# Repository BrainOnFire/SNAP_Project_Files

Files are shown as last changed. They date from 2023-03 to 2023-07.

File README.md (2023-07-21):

# S.N.A.P. Version 6.0

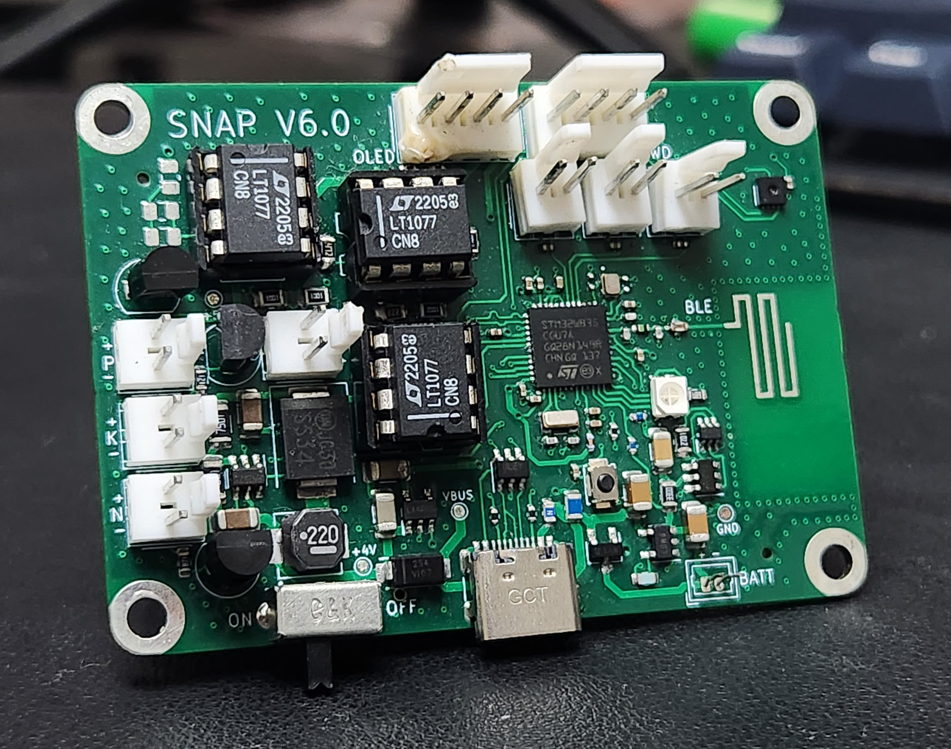
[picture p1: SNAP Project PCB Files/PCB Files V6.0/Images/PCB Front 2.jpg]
</a>

Soil Nutrient Analysis Prototype or S.N.A.P. for short, is an agricultural device that allows farmers to know the best type of nutrient present in a soil sample. The most common types of nutrients found in the ground are Nitrogen, Phosphorus, and Potassium. Photo-sensing sensors can observe these nutrients when an infrared beam hits a sample. Having this information in less than 10 minutes allows the farmer to decide which crop to plant in the selected soil, saving a lot of time and money. The device has come a long way, as this is the sixth iteration of the project. SNAP 6.0 is a BLE, Low-Power, feature-rich sensing device. Here are some specs of the device:

- STM32WB35CCU7A as main MCU (Ultra-low-power dual-core ARM Cortex-M4 with FPU, Bluetooth 5.2, 256KB Flash, 32MHz)
- Integrated Lithium-Ion battery charging with MCP73831 (Charge current 500mA, 4.2V Regulation, Reverse Discharge Protection)
- Battery protection using AP9101C (overcharge voltage, over-discharge voltage, overcharge current, over-discharge current)
- Boost Converter from 3.0V to 5.2V using MT3608 (turns on/off by MCU)
- Temperature and humidity sensing using SHT31-DIS
- OLED Screen for displaying information with low consumption
- PCB Antenna with impedance matching for Bluetooth Low Energy
- USB Type-C 2.0 for 5V power supply and communication

## PCB Design
The design and development of the printed circuit board were done using KiCAD 6.0. The PCB in question is a 4-layer board with a thickness of 1.62 mm and overall dimensions of 66.80 mm x 47.34 mm. The layer stack up is Signal - Ground - Ground - Mixed. 

A USB-C Type Receptacle was used for the power supply coupled with a USBLC6-2SC6 ESD protection chip. Serial Wire is used for the programming of the STM32 chip. A MOSFET and a Schottky Diode are used in order to protect the device when both battery and USB are connected and supply power to the system. Both inputs are regulated by the ADP121 LDO which outputs a voltage of 3.0V to the MCU and to the boost-up converter. The amplification system, the three IR LEDs, the Phototransistor, the SHT31, and the OLED screen are supplied by the 5.2V outputted by the boost-up converter MT3608. Three 2N700 MOSFETs are used to control the IR LEDs through the MCU. 

A total of 27 decoupling capacitors of different values and sizes are used to filter unwanted frequencies. 

A filter PI and RF Band Pass filter are used for the 2.4GHz PCB BLE antenna. The values of capacitance and inductance were calculated using the impedance of the PCB antenna (obtained from [AN5129](https://www.st.com/resource/en/application_note/an5129-low-cost-pcb-antenna-for-24ghz-radio-meander-design-for-stm32wb-series-stmicroelectronics.pdf)), in order to obtain a matching impedance of 50 ohms. The next two images show the first and second pages of the schematic; every part of the device is clearly named.

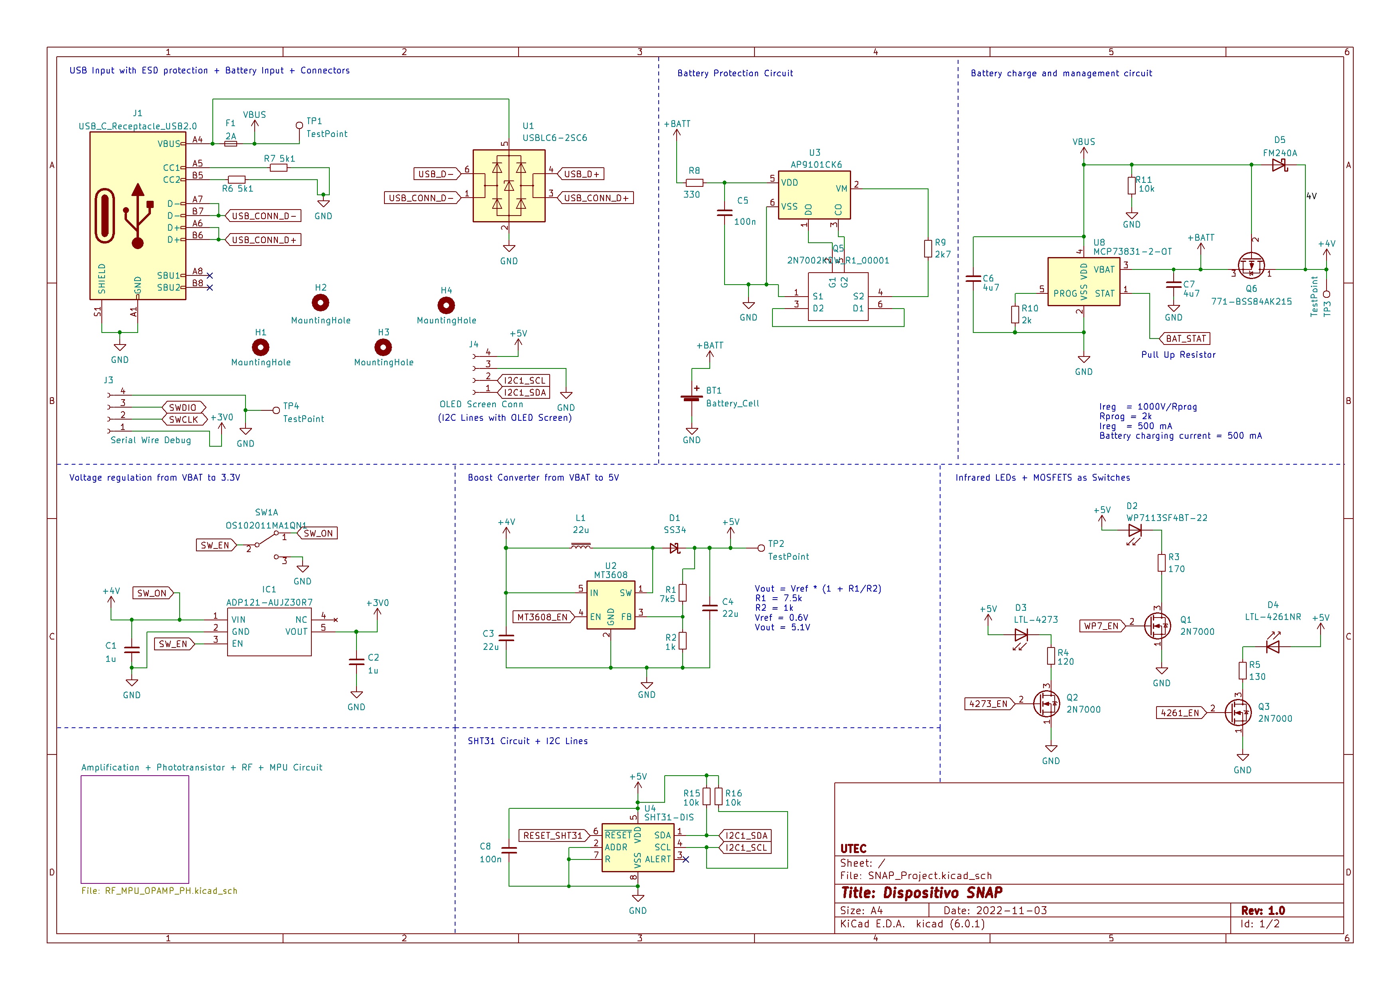
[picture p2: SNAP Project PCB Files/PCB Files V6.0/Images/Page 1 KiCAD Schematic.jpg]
</a>
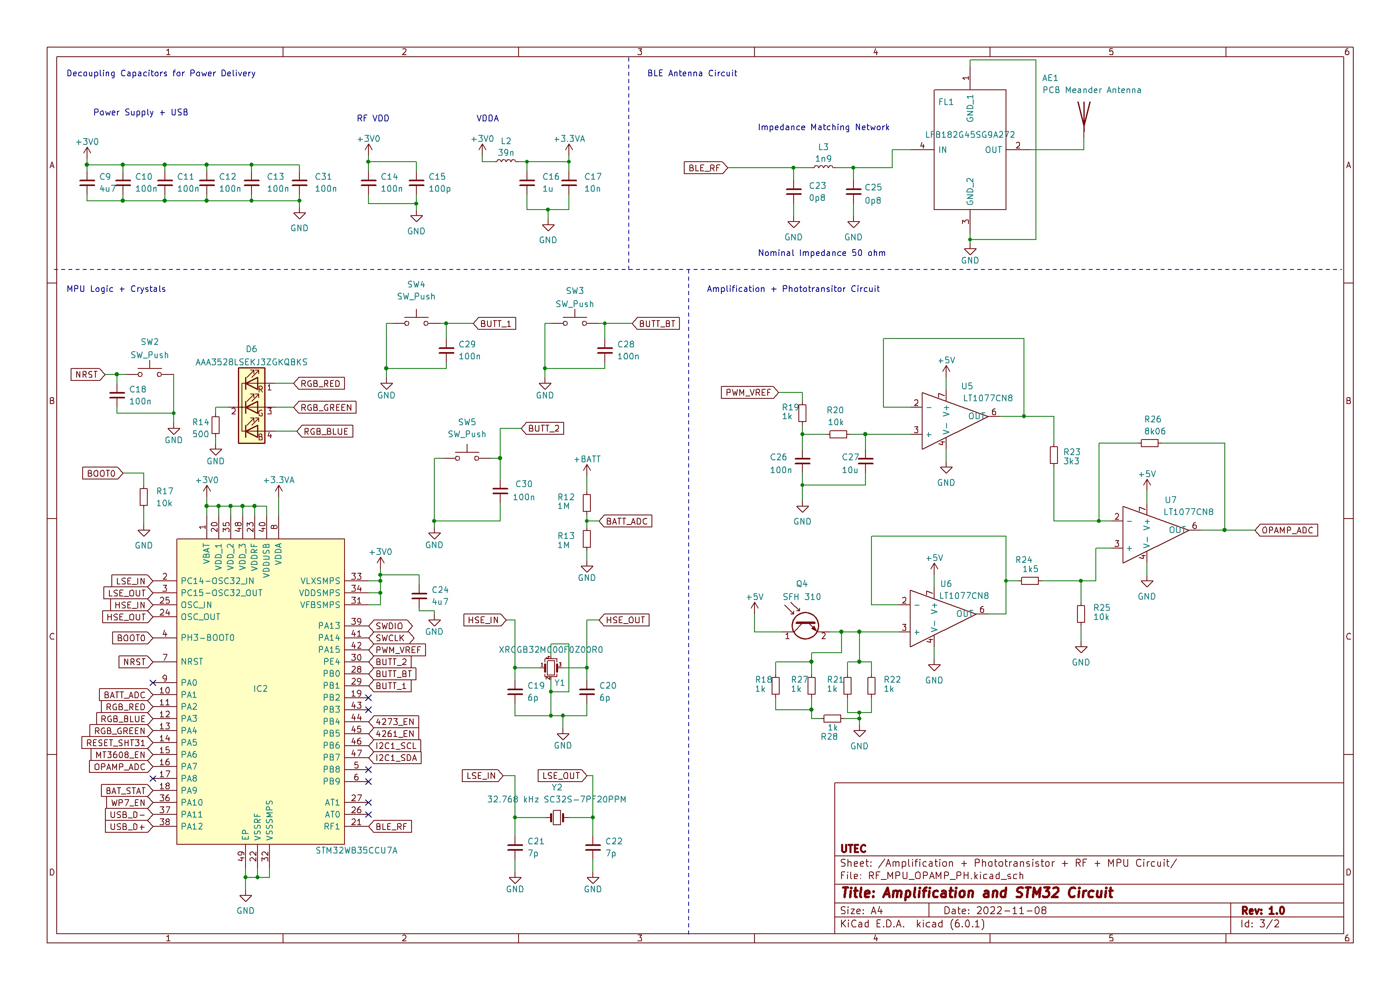
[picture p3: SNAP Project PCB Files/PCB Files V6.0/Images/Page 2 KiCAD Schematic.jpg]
</a>

This PCB was manufactured by JLCPCB using the controlled impedance stack up JLC04161H-7628 for a dielectric constant of 4.6. This provides a matching impedance of 50 ohm for the traces of the embedded antenna that mitigate potential power losses due to parasitic capacitances. The SMD components were soldered using an SMD reflow process with a heat gun.

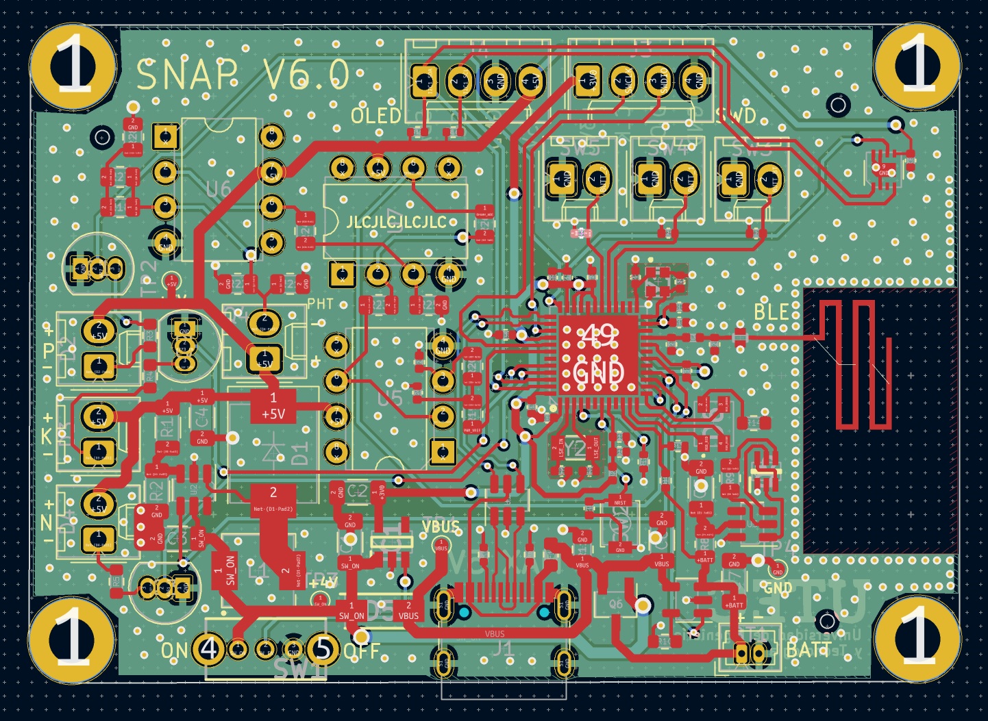
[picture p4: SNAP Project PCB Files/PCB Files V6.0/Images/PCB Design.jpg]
</a>
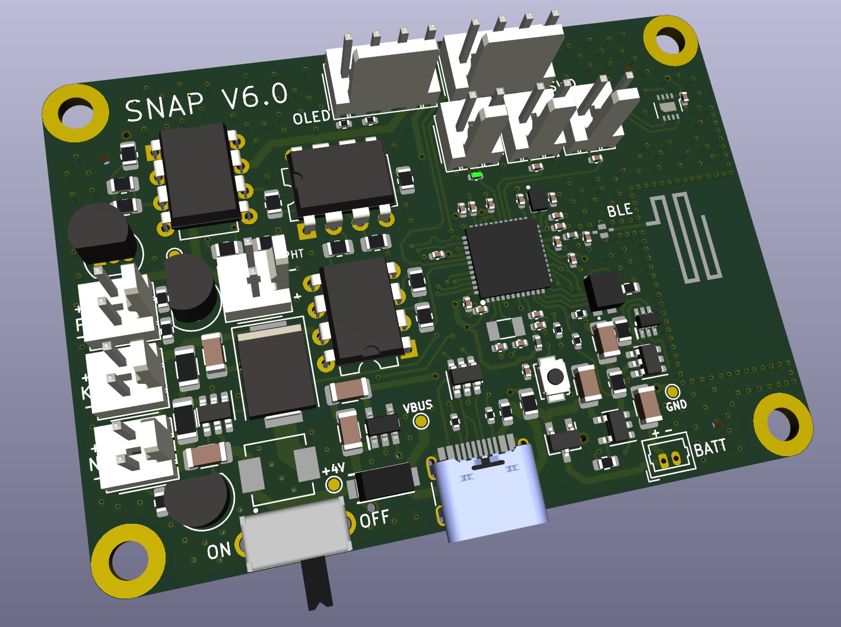
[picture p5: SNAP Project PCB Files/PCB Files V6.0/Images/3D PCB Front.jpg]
</a>

Most of the components were selected for the sole purpose of low energy consumption. The battery selected was a 2500mAh LiPo battery which can be charged through the device's USB type C. With this battery capacity, the device is capable of lasting for almost 30 days without charging, while being completely on. If the device's switch is turned OFF, the battery can last for almost a year and a half without the need for charging. Using a special Fluke Ammeter the total consumption of the device in this state is 185nA. This consumption happens because the device is not completely OFF; some components of the battery's charging system and the LDO are still drawing some current. The challenge of this device's design was keeping the consumption to a minimum. The team is very satisfied with the results.

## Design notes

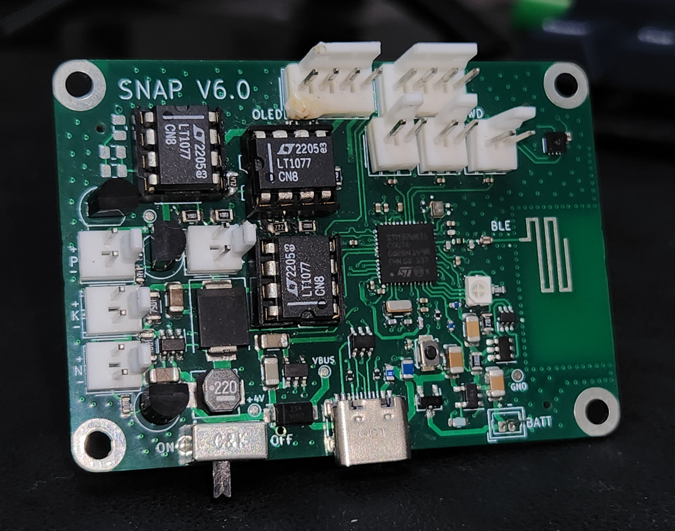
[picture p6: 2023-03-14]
SNAP Project PCB Files/PCB Files V6.0/Images/PCB Front 1.jpg

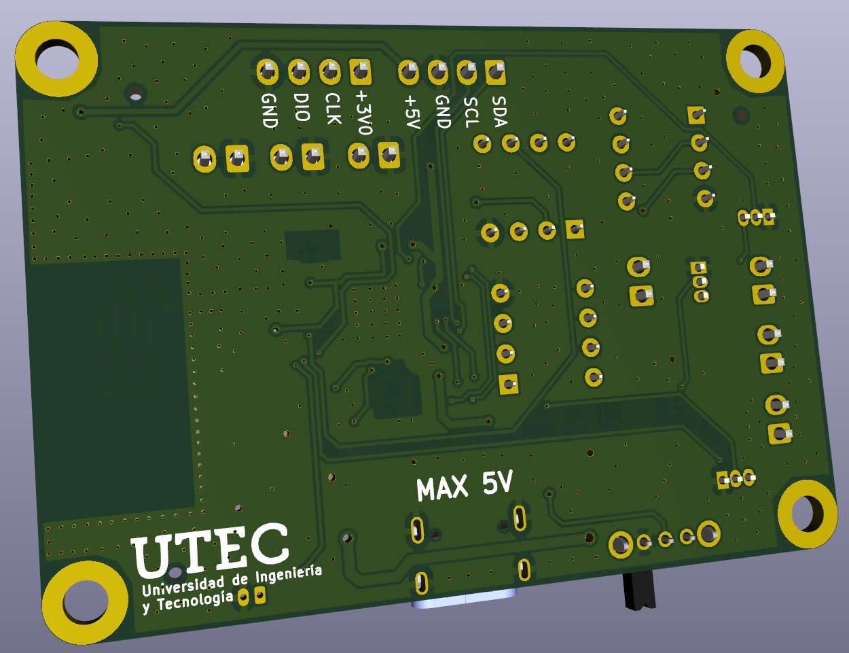
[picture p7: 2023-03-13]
SNAP Project PCB Files/PCB Files V6.0/Images/3D PCB Back.jpg

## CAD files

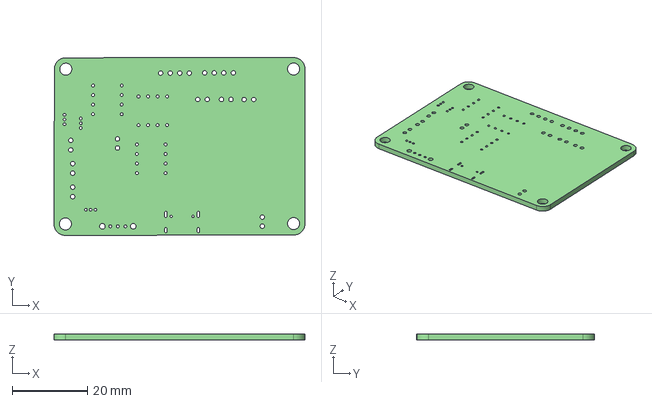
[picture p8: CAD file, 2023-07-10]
SNAP Project PCB Files/PCB Files V6.0/3D Files/SNAP_Project.step
66.7 x 47.2 x 1.63 mm

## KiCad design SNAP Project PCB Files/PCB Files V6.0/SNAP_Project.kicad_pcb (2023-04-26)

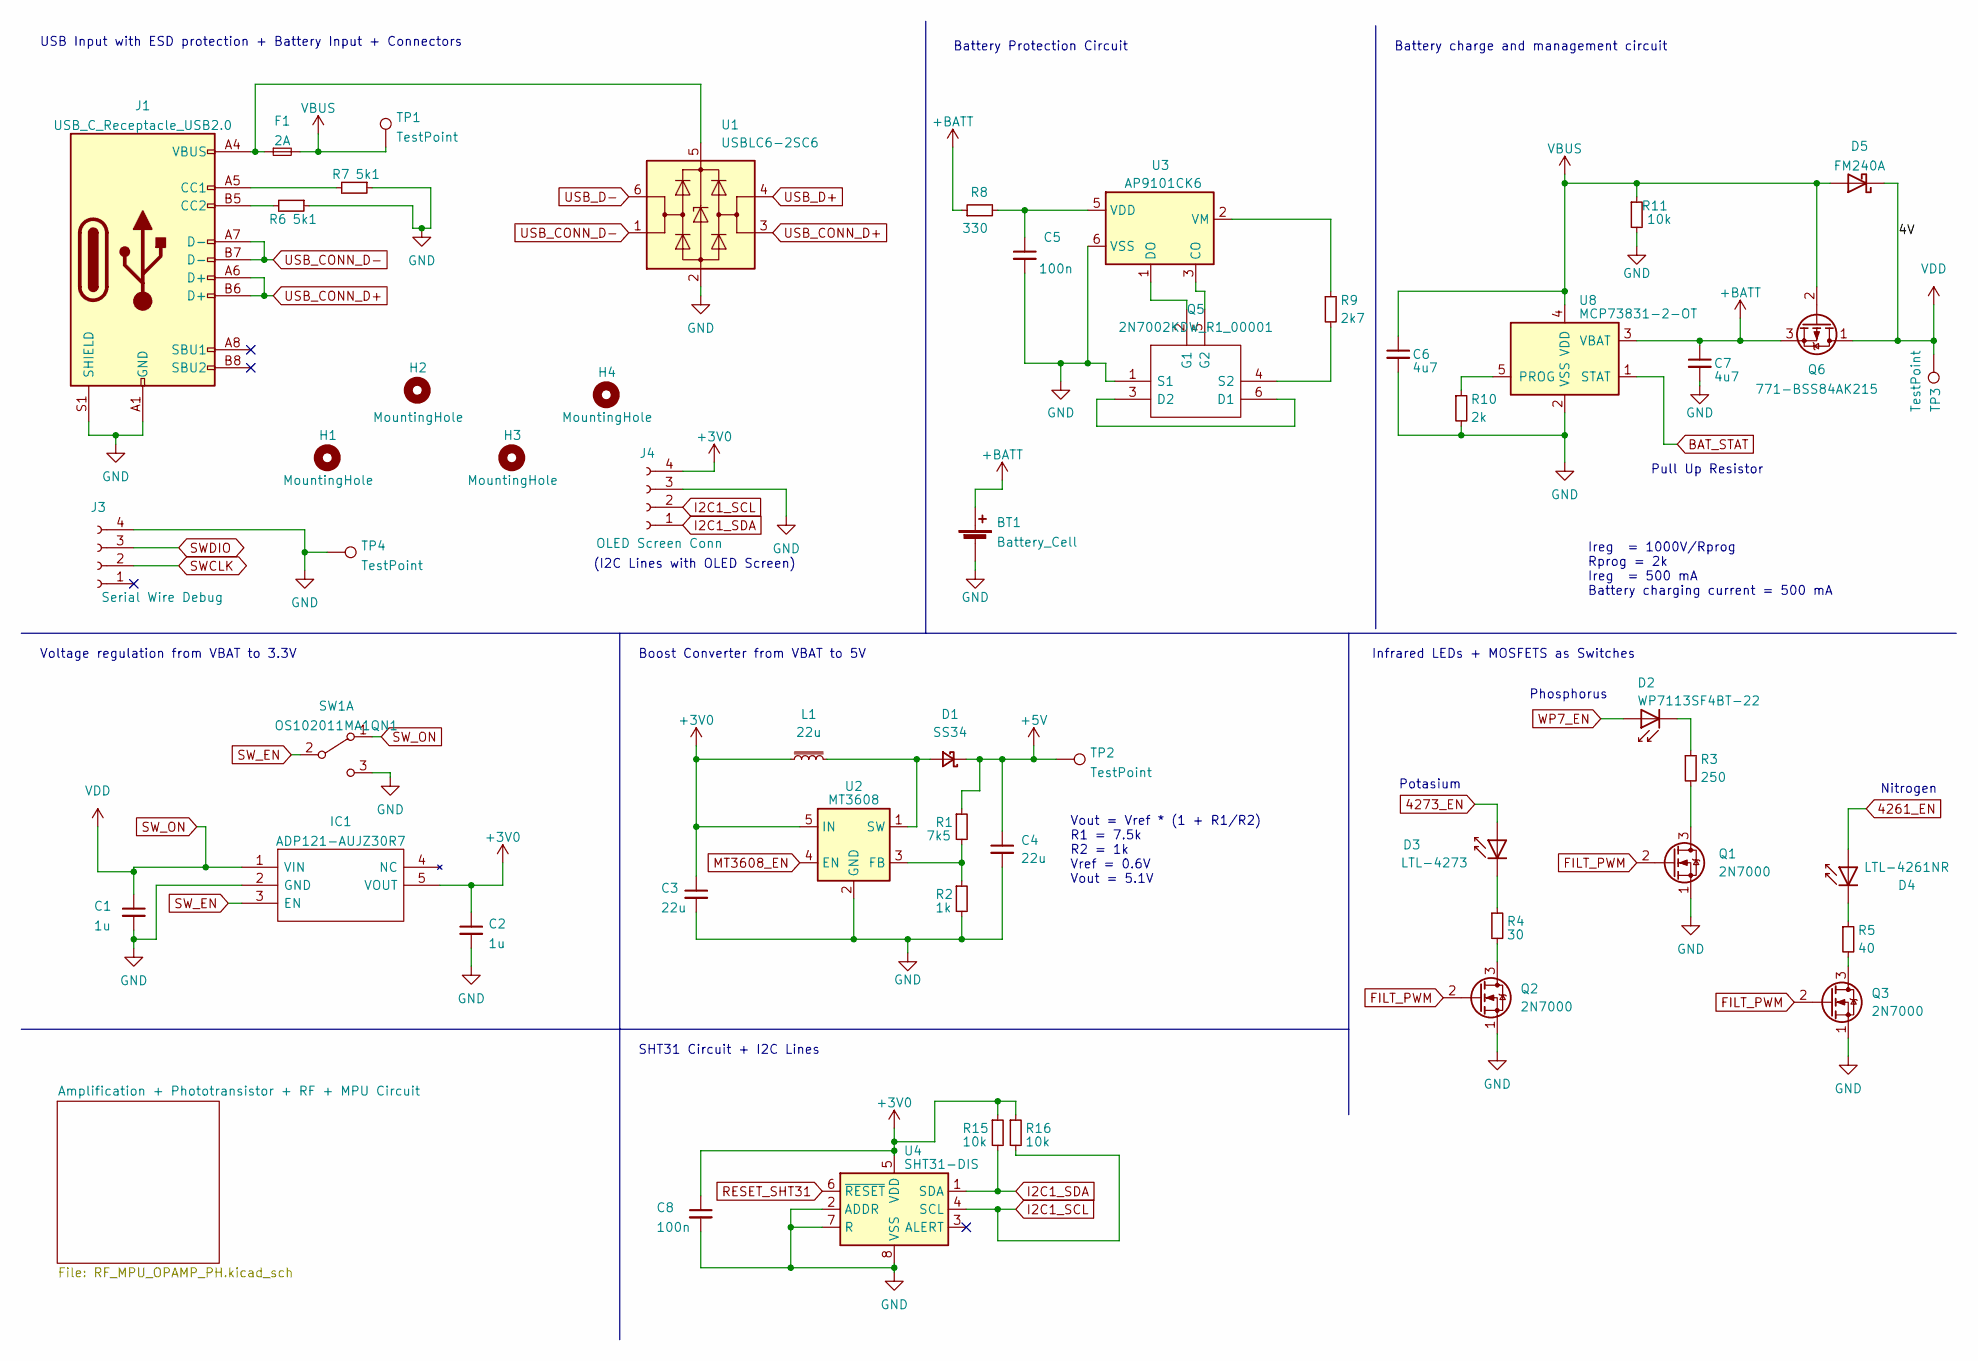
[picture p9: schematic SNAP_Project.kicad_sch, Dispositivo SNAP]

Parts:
BT1: Battery_Cell; Molex_KK-254_AE-6410-02A_1x02_P2.54mm_Vertical
C1, C2: 1u; C_1206_3216Metric
C3, C4: 22u; C_1206_3216Metric
C5: 100n; C_1206_3216Metric
C6, C7: 4u7; C_1206_3216Metric
C8: 100n; C_0402_1005Metric
D1: SS34; D_SMC
D2: WP7113SF4BT-22; Molex_KK-254_AE-6410-02A_1x02_P2.54mm_Vertical
D3: LTL-4273; Molex_KK-254_AE-6410-02A_1x02_P2.54mm_Vertical
D4: LTL-4261NR; Molex_KK-254_AE-6410-02A_1x02_P2.54mm_Vertical
D5: FM240A; DIOM5025X231N
F1: 2A; Fuse_0603_1608Metric; Mouser Code MFU0603FF02000P500
H1, H2, H3, H4: MountingHole; MountingHole_3mm_Pad
IC1: ADP121-AUJZ30R7; SOT95P280X100-5N; Mouser Part Number 584-ADP121-AUJZ33R7
J1: USB_C_Receptacle_USB2.0; USB_C_Receptacle_HRO_TYPE-C-31-M-12
J3: Serial Wire Debug; Molex_KK-254_AE-6410-04A_1x04_P2.54mm_Vertical
J4: OLED Screen Conn; Molex_KK-254_AE-6410-04A_1x04_P2.54mm_Vertical
L1: 22u; L_Vishay_IHLP-2020
Q1, Q2, Q3: 2N7000; TO-92_Inline
Q5: 2N7002KDW_R1_00001; SOT65P210X110-6N; Mouser Part Number 241-2N7002KDWR100001
Q6: 771-BSS84AK215; TSOT-23
R1: 7k5; R_1206_3216Metric
R2: 1k; R_1206_3216Metric
R3: 250; R_0805_2012Metric
R4: 30; R_0603_1608Metric
R5: 40; R_0603_1608Metric
R6, R7: 5k1; R_0402_1005Metric
R8: 330; R_0805_2012Metric
R9: 2k7; R_0805_2012Metric
R10: 2k; R_0603_1608Metric
R11: 10k; R_0805_2012Metric
R15, R16: 10k; R_0402_1005Metric
SW1: OS102011MA1QN1
TP1, TP2, TP3, TP4: TestPoint; TestPoint_Pad_D1.0mm
U1: USBLC6-2SC6; SOT-23-6
U2: MT3608; SOT-23-6
U3: AP9101CK6; SOT-23-6
U4: SHT31-DIS; Sensirion_DFN-8-1EP_2.5x2.5mm_P0.5mm_EP1.1x1.7mm
U8: MCP73831-2-OT; SOT-23-5

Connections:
4261_EN: D4.2 (A); also elsewhere on the board
4273_EN: D3.2 (A); also elsewhere on the board
+3V0: C2.1, C3.1, C8.1, IC1.5 (VOUT), J4.4, L1.1, R15.1, R16.1, U2.5 (IN), U4.5 (VDD); also elsewhere on the board
+5V: C4.1, D1.1 (K), R1.1, TP2.1; also elsewhere on the board
+BATT: BT1.1 (+), C7.1, Q6.3 (S), R8.1, U8.3 (VBAT); also elsewhere on the board
BAT_STAT: U8.1 (STAT); also elsewhere on the board
FILT_PWM: Q1.2 (G), Q2.2 (G), Q3.2 (G); also elsewhere on the board
GND: BT1.2 (-), C1.2, C2.2, C3.2, C4.2, C5.2, C6.2, C7.2, C8.2, IC1.2 (GND), J1.A1 (GND), J1.A12 (GND), J1.B1 (GND), J1.B12 (GND), J1.S1 (SHIELD), J3.4, J4.3, Q1.1 (S), Q2.1 (S), Q3.1 (S), Q5.1 (S1), R2.2, R6.1, R7.1, R10.2, R11.2, SW1.3 (C), TP4.1, U1.2 (GND), U2.2 (GND), U3.6 (VSS), U4.2 (ADDR), U4.7 (R), U4.8 (VSS), U4.9 (VSS), U8.2 (VSS); also elsewhere on the board
I2C1_SCL: J4.2, R16.2, U4.4 (SCL); also elsewhere on the board
I2C1_SDA: J4.1, R15.2, U4.1 (SDA); also elsewhere on the board
MT3608_EN: U2.4 (EN); also elsewhere on the board
unnamed: C5.1, R8.2, U3.5 (VDD)
unnamed: D1.2 (A), L1.2, U2.1 (SW)
unnamed: D2.1 (K), R3.1
unnamed: D3.1 (K), R4.1
unnamed: D4.1 (K), R5.1
unnamed: F1.1, J1.A4 (VBUS), J1.A9 (VBUS), J1.B4 (VBUS), J1.B9 (VBUS), U1.5 (VBUS)
unnamed: J1.A5 (CC1), R7.2
unnamed: J1.B5 (CC2), R6.2
unnamed: Q1.3 (D), R3.2
unnamed: Q2.3 (D), R4.2
unnamed: Q3.3 (D), R5.2
unnamed: Q5.2 (G1), U3.1 (DO)
unnamed: Q5.3 (D2), Q5.6 (D1)
unnamed: Q5.4 (S2), R9.2
unnamed: Q5.5 (G2), U3.3 (CO)
unnamed: R1.2, R2.1, U2.3 (FB)
unnamed: R9.1, U3.2 (VM)
unnamed: R10.1, U8.5 (PROG)
RESET_SHT31: U4.6 (~RESET); also elsewhere on the board
SWCLK: J3.2; also elsewhere on the board
SWDIO: J3.3; also elsewhere on the board
SW_EN: IC1.3 (EN), SW1.2 (B)
SW_ON: C1.1, D5.1 (K), IC1.1 (VIN), Q6.1 (D), SW1.1 (A), TP3.1
USB_CONN_D+: J1.A6 (D+), J1.B6 (D+), U1.3 (I/O2)
USB_CONN_D-: J1.A7 (D-), J1.B7 (D-), U1.1 (I/O1)
USB_D+: U1.4 (I/O2); also elsewhere on the board
USB_D-: U1.6 (I/O1); also elsewhere on the board
VBUS: C6.1, D5.2 (A), F1.2, Q6.2 (G), R11.1, TP1.1, U8.4 (VDD)
WP7_EN: D2.2 (A); also elsewhere on the board

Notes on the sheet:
Boost Converter from VBAT to 5V
(I2C Lines with OLED Screen)
Ireg = 1000V/Rprog Rprog = 2k Ireg = 500 mA Battery charging current = 500 mA
Voltage regulation from VBAT to 3.3V
Potasium
Vout = Vref * (1 + R1/R2) R1 = 7.5k R2 = 1k Vref = 0.6V Vout = 5.1V
SHT31 Circuit + I2C Lines
USB Input with ESD protection + Battery Input + Connectors
Phosphorus
Pull Up Resistor
Nitrogen
Battery Protection Circuit
Battery charge and management circuit
Infrared LEDs + MOSFETS as Switches

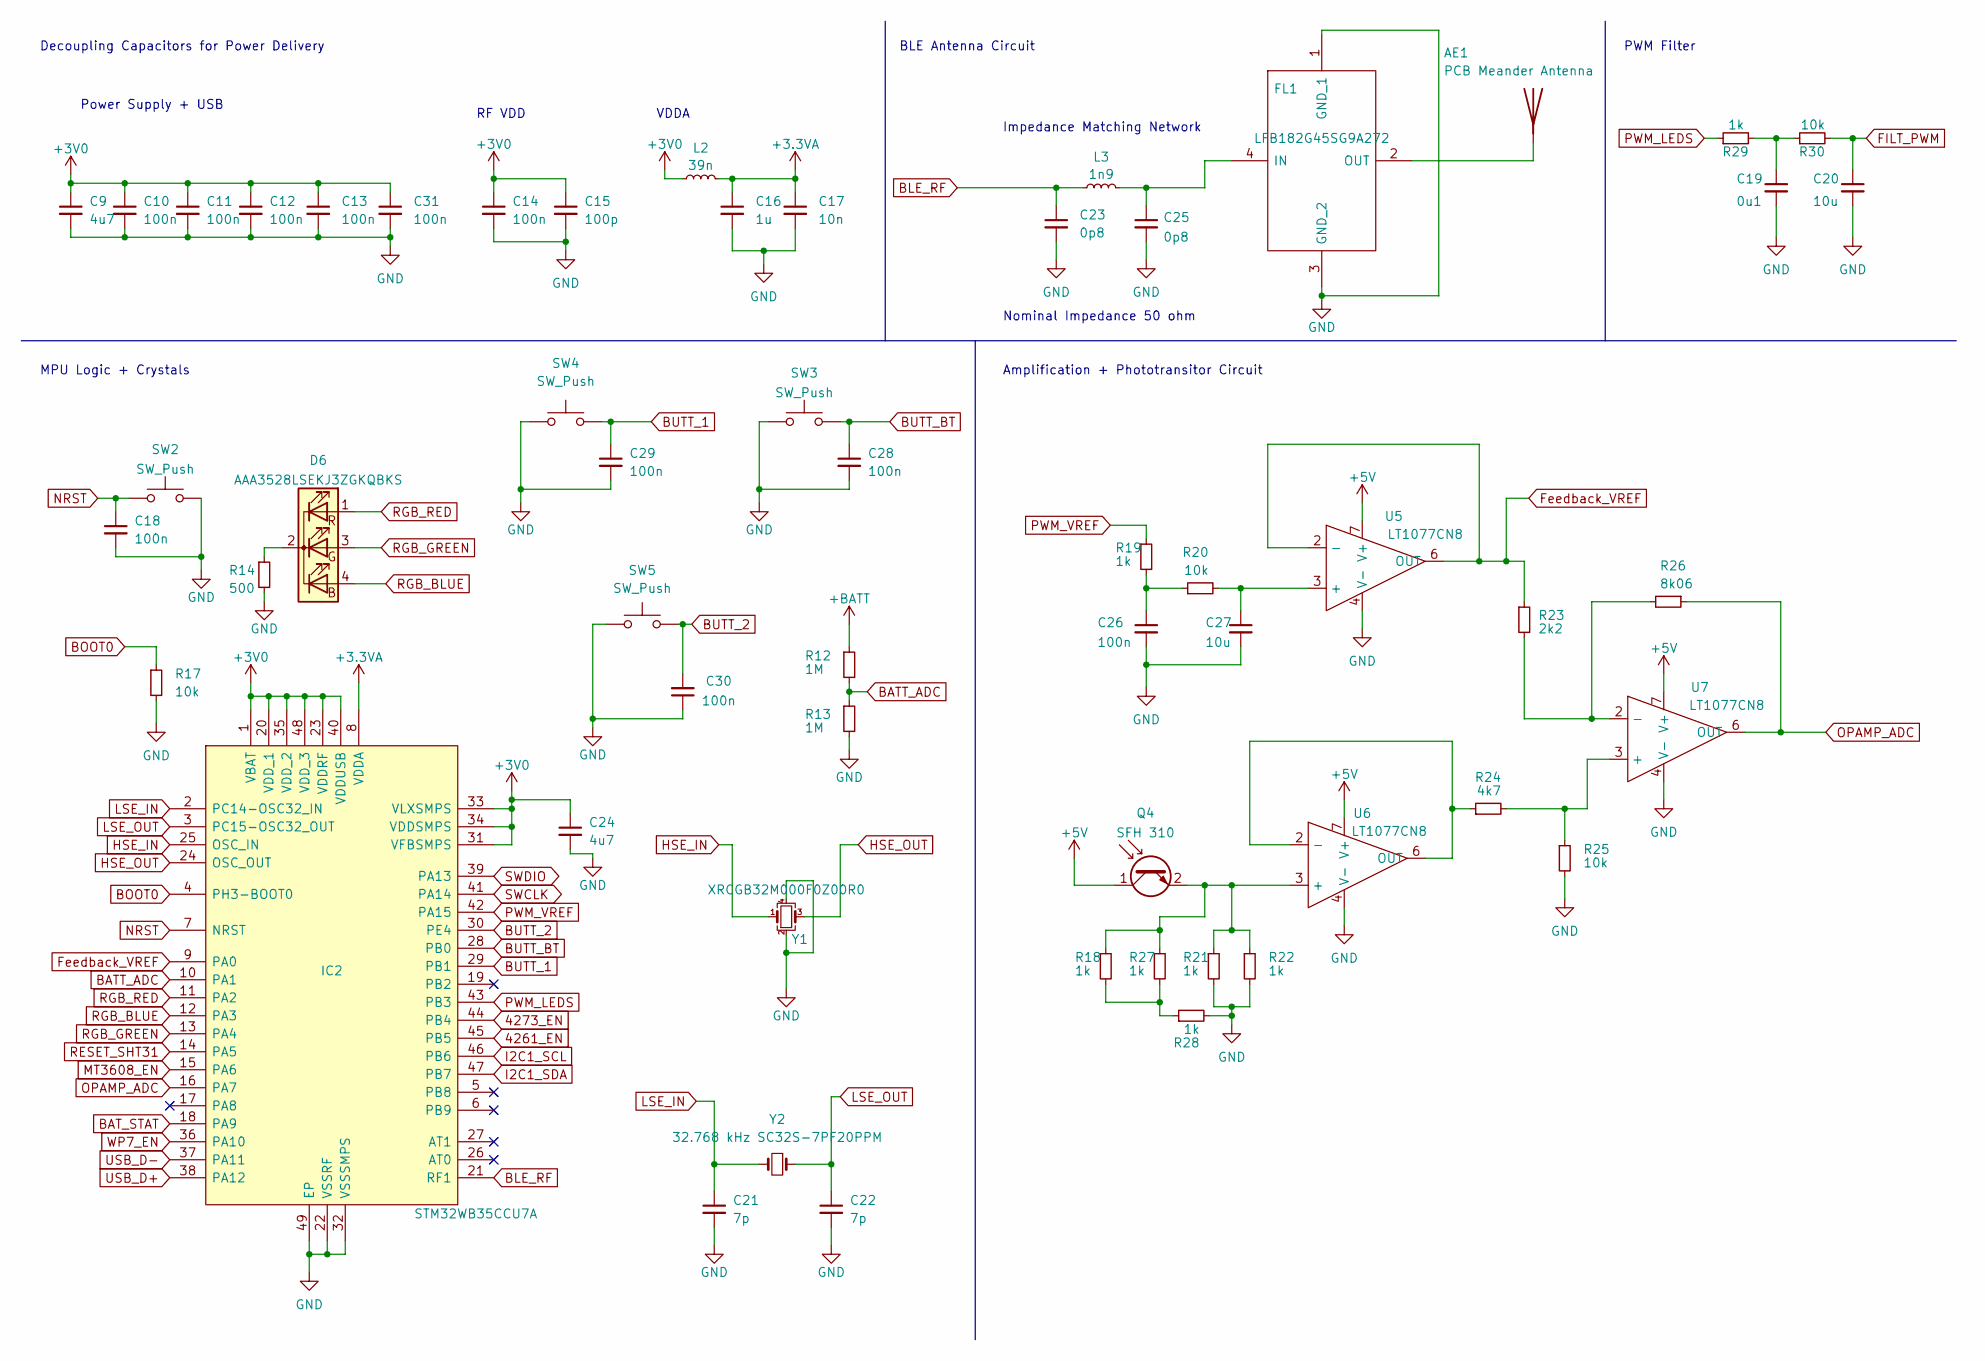
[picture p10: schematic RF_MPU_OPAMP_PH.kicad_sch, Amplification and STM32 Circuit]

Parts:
AE1: PCB Meander Antenna
C9, C24: 4u7; C_0402_1005Metric
C10, C11, C12, C13, C14, C26, C31: 100n; C_0402_1005Metric
C15: 100p; C_0402_1005Metric
C16: 1u; C_0402_1005Metric
C17: 10n; C_0402_1005Metric
C18, C28, C29, C30: 100n; C_0402_1005Metric; LCSC Part # C307331
C19: 0u1; C_0402_1005Metric
C20, C27: 10u; C_0402_1005Metric
C21, C22: 7p; C_0402_1005Metric; LCSC Part # C307331
C23, C25: 0p8; C_0402_1005Metric
D6: AAA3528LSEKJ3ZGKQBKS
FL1: LFB182G45SG9A272; Mouser Part Number 81-LFB182G45SG9A272
IC2: STM32WB35CCU7A; QFN50P700X700X65-49N-D; Mouser Part Number 511-STM32WB35CCU7A
L2: 39n; L_0402_1005Metric
L3: 1n9; L_0402_1005Metric
Q4: SFH 310; Molex_KK-254_AE-6410-02A_1x02_P2.54mm_Vertical
R12, R13: 1M; R_0402_1005Metric
R14: 500; R_0603_1608Metric; LCSC Part # C25744
R17: 10k; R_0402_1005Metric; LCSC Part # C25744
R18, R19, R21, R22, R27, R28, R29: 1k; R_0805_2012Metric
R20, R25, R30: 10k; R_0805_2012Metric
R23: 2k2; R_0805_2012Metric
R24: 4k7; R_0805_2012Metric
R26: 8k06; R_0805_2012Metric
SW2: SW_Push; SW_SPST_B3U-1000P; LCSC Part # B3U-1000P
SW3, SW4, SW5: SW_Push; Molex_KK-254_AE-6410-02A_1x02_P2.54mm_Vertical; LCSC Part # B3U-1000P
U5, U6, U7: LT1077CN8; DIP-8_W7.62mm
Y1: XRCGB32M000F0Z00R0
Y2: 32.768 kHz SC32S-7PF20PPM; Crystal_SMD_3215-2Pin_3.2x1.5mm

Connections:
4261_EN: IC2.45 (PB5); also elsewhere on the board
4273_EN: IC2.44 (PB4); also elsewhere on the board
+3.3VA: C16.1, C17.1, IC2.8 (VDDA), L2.2
+3V0: C9.1, C10.1, C11.1, C12.1, C13.1, C14.1, C15.1, C24.1, C31.1, IC2.1 (VBAT), IC2.20 (VDD_1), IC2.23 (VDDRF), IC2.31 (VFBSMPS), IC2.33 (VLXSMPS), IC2.34 (VDDSMPS), IC2.35 (VDD_2), IC2.40 (VDDUSB), IC2.48 (VDD_3), L2.1; also elsewhere on the board
+5V: Q4.1 (C), U5.7 (V+), U6.7 (V+), U7.7 (V+); also elsewhere on the board
+BATT: R12.1; also elsewhere on the board
BATT_ADC: IC2.10 (PA1), R12.2, R13.1
BAT_STAT: IC2.18 (PA9); also elsewhere on the board
BLE_RF: C23.1, IC2.21 (RF1), L3.1
BOOT0: IC2.4 (PH3-BOOT0), R17.1
BUTT_1: C29.1, IC2.29 (PB1), SW4.2
BUTT_2: C30.2, IC2.30 (PE4), SW5.2
BUTT_BT: C28.1, IC2.28 (PB0), SW3.2
FILT_PWM: C20.1, R30.2; also elsewhere on the board
Feedback_VREF: IC2.9 (PA0), R23.1, U5.2 (-), U5.6 (OUT)
GND: C9.2, C10.2, C11.2, C12.2, C13.2, C14.2, C15.2, C16.2, C17.2, C18.2, C19.2, C20.2, C21.2, C22.2, C23.2, C24.2, C25.2, C26.2, C27.2, C28.2, C29.2, C30.1, C31.2, FL1.1 (GND_1), FL1.3 (GND_2), IC2.22 (VSSRF), IC2.32 (VSSSMPS), IC2.49 (EP), R13.2, R14.2, R17.2, R21.2, R22.2, R25.2, R28.2, SW2.2, SW3.1, SW4.1, SW5.1, U5.4 (V-), U6.4 (V-), U7.4 (V-), Y1.2, Y1.4; also elsewhere on the board
HSE_IN: IC2.25 (OSC_IN), Y1.1
HSE_OUT: IC2.24 (OSC_OUT), Y1.3
I2C1_SCL: IC2.46 (PB6); also elsewhere on the board
I2C1_SDA: IC2.47 (PB7); also elsewhere on the board
LSE_IN: C21.1, IC2.2 (PC14-OSC32_IN), Y2.2
LSE_OUT: C22.1, IC2.3 (PC15-OSC32_OUT), Y2.1
MT3608_EN: IC2.15 (PA6); also elsewhere on the board
NRST: C18.1, IC2.7 (NRST), SW2.1
unnamed: AE1.1 (A), FL1.2 (OUT)
unnamed: C19.1, R29.2, R30.1
unnamed: C25.1, FL1.4 (IN), L3.2
unnamed: C26.1, R19.2, R20.1
unnamed: C27.1, R20.2, U5.3 (+)
unnamed: D6.2 (K), R14.1
unnamed: Q4.2 (E), R18.1, R21.1, R22.1, R27.1, U6.3 (+)
unnamed: R18.2, R27.2, R28.1
unnamed: R23.2, R26.2, U7.2 (-)
unnamed: R24.1, U6.2 (-), U6.6 (OUT)
unnamed: R24.2, R25.1, U7.3 (+)
OPAMP_ADC: IC2.16 (PA7), R26.1, U7.6 (OUT)
PWM_LEDS: IC2.43 (PB3), R29.1
PWM_VREF: IC2.42 (PA15), R19.1
RESET_SHT31: IC2.14 (PA5); also elsewhere on the board
RGB_BLUE: D6.4 (BA), IC2.12 (PA3)
RGB_GREEN: D6.3 (GA), IC2.13 (PA4)
RGB_RED: D6.1 (RA), IC2.11 (PA2)
SWCLK: IC2.41 (PA14); also elsewhere on the board
SWDIO: IC2.39 (PA13); also elsewhere on the board
USB_D+: IC2.38 (PA12); also elsewhere on the board
USB_D-: IC2.37 (PA11); also elsewhere on the board
WP7_EN: IC2.36 (PA10); also elsewhere on the board

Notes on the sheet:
Decoupling Capacitors for Power Delivery
BLE Antenna Circuit
Nominal Impedance 50 ohm
RF VDD
PWM Filter
Power Supply + USB
Impedance Matching Network
MPU Logic + Crystals
VDDA
Amplification + Phototransitor Circuit

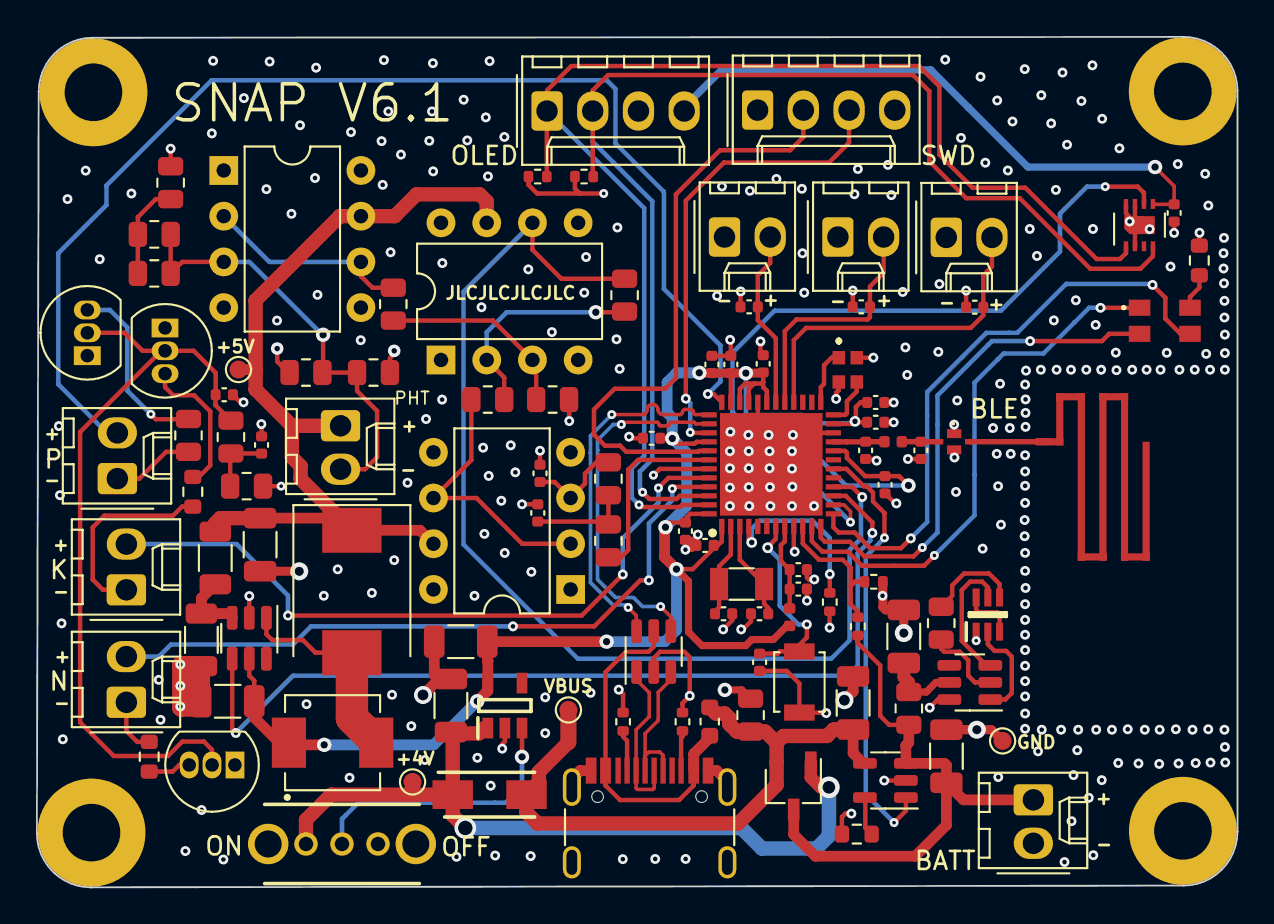
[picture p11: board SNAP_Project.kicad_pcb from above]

Board: 4 copper layers, 66.7 x 47.2 mm, 108 parts (0 on the bottom side), 70 nets.

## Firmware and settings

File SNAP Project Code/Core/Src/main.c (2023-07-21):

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
/* Includes ------------------------------------------------------------------*/
#include "main.h"
#include "usb_device.h"

/* USER CODE BEGIN Includes */
#include "sht31.h"
#include <stdio.h>
#include "stm32_seq.h"
#include "fonts.h"
#include "ssd1306.h"
#include "usb_device.h"
#include "custom_app.h"
/* USER CODE END Includes */

ADC_HandleTypeDef hadc1;
DMA_HandleTypeDef hdma_adc1;

I2C_HandleTypeDef hi2c1;

IPCC_HandleTypeDef hipcc;

RTC_HandleTypeDef hrtc;

TIM_HandleTypeDef htim2;

/* USER CODE BEGIN PV */
uint8_t battery_completed = 0;
/* USER CODE END PV */

void SystemClock_Config(void);
void PeriphCommonClock_Config(void);
static void MX_GPIO_Init(void);
static void MX_DMA_Init(void);
static void MX_ADC1_Init(void);
static void MX_I2C1_Init(void);
static void MX_IPCC_Init(void);
static void MX_RTC_Init(void);
static void MX_TIM2_Init(void);
static void MX_RF_Init(void);
/**
  * @brief  The application entry point.
  * @retval int
  */
int main(void)
{
  /* MCU Configuration--------------------------------------------------------*/

  /* Reset of all peripherals, Initializes the Flash interface and the Systick. */
  HAL_Init();
  /* Config code for STM32_WPAN (HSE Tuning must be done before system clock configuration) */
  MX_APPE_Config();

  /* Configure the system clock */
  SystemClock_Config();

/* Configure the peripherals common clocks */
  PeriphCommonClock_Config();

  /* IPCC initialisation */
  MX_IPCC_Init();

  /* Initialize all configured peripherals */
  MX_GPIO_Init();
  MX_DMA_Init();
  MX_USB_Device_Init();
  MX_ADC1_Init();
  MX_I2C1_Init();
  MX_RTC_Init();
  MX_TIM2_Init();
  MX_RF_Init();
  /* USER CODE BEGIN 2 */
  HAL_GPIO_WritePin(GPIOA, MT3608_EN_Pin, GPIO_PIN_SET); 	/* Toggle 5V rail */
  SSD1306_Init();											/* Init OLED Screen */
  /* USER CODE END 2 */

  /* Init code for STM32_WPAN */
  MX_APPE_Init();

  /* Infinite loop */
  /* USER CODE BEGIN WHILE */

  while (1)
  {
    /* USER CODE END WHILE */
    MX_APPE_Process();	//Enters to the SNAP Application. Please refer to the file SNAP_Project_Code -> STM32_WPAN -> App -> custom_app.c

    /* USER CODE BEGIN 3 */
  }
  /* USER CODE END 3 */
}

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
/* USER CODE BEGIN 4 */
void HAL_GPIO_EXTI_Callback(uint16_t GPIO_Pin)
{
	while(GPIO_Pin == BATT_STAT_Pin)
	{
		battery_completed = 1;
		HAL_GPIO_WritePin(GPIOA, RGB_GREEN_Pin, GPIO_PIN_SET);
	}

}
/* USER CODE END 4 */
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


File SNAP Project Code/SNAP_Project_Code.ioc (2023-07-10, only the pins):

Mcu.UserName=STM32WB35CCUxA
PA0.GPIO_Label=Feedback_VREF
PA0.Signal=ADCx_IN5
PA1.GPIO_Label=BATT_ADC
PA1.Signal=ADCx_IN6
PA10.GPIO_Label=LED_WP7_EN
PA10.Signal=GPIO_Output
PA11.Signal=USB_DM
PA12.Signal=USB_DP
PA13.Signal=SYS_JTMS-SWDIO
PA14.Signal=SYS_JTCK-SWCLK
PA15.GPIO_Label=PWM_VREF
PA15.Signal=S_TIM2_CH1
PA2.GPIO_Label=RGB_RED
PA2.Signal=GPIO_Output
PA3.GPIO_Label=RGB_BLUE
PA3.Signal=GPIO_Output
PA4.GPIO_Label=RGB_GREEN
PA4.Signal=GPIO_Output
PA5.GPIO_Label=RESET_SHT31
PA5.Signal=GPIO_Output
PA6.GPIO_Label=MT3608_EN
PA6.Signal=GPIO_Output
PA7.GPIO_Label=OPAMP_ADC
PA7.Signal=ADCx_IN12
PA9.GPIO_Label=BATT_STAT
PA9.Signal=GPXTI9
PB0.GPIO_Label=BUTT_BT
PB0.Signal=GPIO_Input
PB1.GPIO_Label=BUTT_1
PB1.Signal=GPIO_Input
PB3.GPIO_Label=PWM_LEDS
PB3.Signal=S_TIM2_CH2
PB4.GPIO_Label=LED_4273_EN
PB4.Signal=GPIO_Output
PB5.GPIO_Label=LED_4261_EN
PB5.Signal=GPIO_Output
PB6.Signal=I2C1_SCL
PB7.Signal=I2C1_SDA
PC14-OSC32_IN.Signal=RCC_OSC32_IN
PC15-OSC32_OUT.Signal=RCC_OSC32_OUT
PE4.GPIO_Label=BUTT_2
PE4.Signal=GPIO_Input

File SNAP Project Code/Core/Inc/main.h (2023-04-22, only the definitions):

#define Feedback_VREF_Pin GPIO_PIN_0
#define Feedback_VREF_GPIO_Port GPIOA
#define BATT_ADC_Pin GPIO_PIN_1
#define BATT_ADC_GPIO_Port GPIOA
#define RGB_RED_Pin GPIO_PIN_2
#define RGB_RED_GPIO_Port GPIOA
#define RGB_BLUE_Pin GPIO_PIN_3
#define RGB_BLUE_GPIO_Port GPIOA
#define RGB_GREEN_Pin GPIO_PIN_4
#define RGB_GREEN_GPIO_Port GPIOA
#define RESET_SHT31_Pin GPIO_PIN_5
#define RESET_SHT31_GPIO_Port GPIOA
#define MT3608_EN_Pin GPIO_PIN_6
#define MT3608_EN_GPIO_Port GPIOA
#define OPAMP_ADC_Pin GPIO_PIN_7
#define OPAMP_ADC_GPIO_Port GPIOA
#define BATT_STAT_Pin GPIO_PIN_9
#define BATT_STAT_GPIO_Port GPIOA
#define BATT_STAT_EXTI_IRQn EXTI9_5_IRQn
#define BUTT_BT_Pin GPIO_PIN_0
#define BUTT_BT_GPIO_Port GPIOB
#define BUTT_1_Pin GPIO_PIN_1
#define BUTT_1_GPIO_Port GPIOB
#define BUTT_2_Pin GPIO_PIN_4
#define BUTT_2_GPIO_Port GPIOE
#define LED_WP7_EN_Pin GPIO_PIN_10
#define LED_WP7_EN_GPIO_Port GPIOA
#define PWM_VREF_Pin GPIO_PIN_15
#define PWM_VREF_GPIO_Port GPIOA
#define PWM_LEDS_Pin GPIO_PIN_3
#define PWM_LEDS_GPIO_Port GPIOB
#define LED_4273_EN_Pin GPIO_PIN_4
#define LED_4273_EN_GPIO_Port GPIOB
#define LED_4261_EN_Pin GPIO_PIN_5
#define LED_4261_EN_GPIO_Port GPIOB

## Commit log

2023-03-12 Upload PCB 6.0 Files
    [RF_MPU_OPAMP_PH.kicad_sch, SNAP_Project.kicad_pcb, SNAP_Project.kicad_sch]
2023-03-13 Upload of PCB images
2023-03-13 Fix Button Issue
    [RF_MPU_OPAMP_PH.kicad_sch, SNAP_Project.kicad_pcb, SNAP_Project.kicad_sch]
2023-03-14 4v Line fix
    [RF_MPU_OPAMP_PH.kicad_sch, SNAP_Project.kicad_pcb, SNAP_Project.kicad_sch]
2023-03-15 USB Parity Fix
    [RF_MPU_OPAMP_PH.kicad_sch, SNAP_Project.kicad_pcb]
2023-03-15 USB Fix 2 & 3V line fix
    [SNAP_Project.kicad_pcb, SNAP_Project.kicad_sch]
2023-03-17 OLED Screen Fix & Board corrections
    [RF_MPU_OPAMP_PH.kicad_sch, SNAP_Project.kicad_pcb, SNAP_Project.kicad_sch]
2023-03-21 Fixed Screen & ADC issues
    [SNAP_Project_Code.ioc, custom_app.c, main.c]
2023-04-12 New changes 1.0
    [SNAP_Project.kicad_pcb, SNAP_Project.kicad_sch]
2023-04-22 Updated Connectors, LEDs, filter and STM I/O
    [RF_MPU_OPAMP_PH.kicad_sch, SNAP_Project.kicad_pcb, SNAP_Project.kicad_sch]
2023-04-24 Final Commit V 6.1
    [RF_MPU_OPAMP_PH.kicad_sch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]
2023-04-26 Last Commit before production
    [SNAP_Project-B_Cu.gbr, SNAP_Project-B_Mask.gbr, SNAP_Project-B_Paste.gbr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]
2023-07-10 Update in BT Code
    [SNAP_Project.step]
2023-07-21 Update README.md
    Added some information about the battery and the consumption

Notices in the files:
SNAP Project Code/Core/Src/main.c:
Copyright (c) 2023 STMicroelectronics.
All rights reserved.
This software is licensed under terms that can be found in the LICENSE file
